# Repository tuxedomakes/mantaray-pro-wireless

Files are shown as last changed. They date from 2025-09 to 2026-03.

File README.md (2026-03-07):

# Grab your Mantaray Pro Wireless today from [my Ko-Fi page](https://ko-fi.com/s/1993d29fbd)!

# Mantaray Pro Wireless
This repo contains the build instructions, firmware, and 3D printable files needed to build, understand and modify the Mantaray Pro Wireless keyboard.

Firmware notes:
 - For defining pins higher than D10, you must use &gpioX Y notation (i.e. P1.07 -> &gpio0 7)
 - ZMK revision is currently pinned at v0.03 to avoid breakages in the build by linking to main
 - to use NFC pins as GPIO, CONFIG_NFCT_PINS_AS_GPIOS=y is set in unified .conf

BEGIN DOCUMENTATION

# Mantaray Pro Wireless DIY Edition: Build Guide

Welcome, and congratulations on starting your Mantaray Pro Wireless build! This guide will walk you through every step of the assembly process. Building a keyboard is a uniquely rewarding experience, and we're here to make it as smooth and enjoyable as possible.

**Estimated Build Time:** 1-3 hours  
**Difficulty:** Intermediate  

---

## Before You Begin: The Golden Rule

We know you're excited to get started, but please read this guide in its entirety before touching any components. Some steps require specific procedures and careful attention to detail. Understanding the full process beforehand will save you time and prevent potential mistakes. Trust us on this one!

---

## Part I: Preparation

### 1. Gather Your Tools

A good build starts with the right tools. Here’s what you’ll need to have on hand:

**Required:**
- Soldering Iron (a temperature-controlled model is highly recommended)
- Solder (low-temp, leaded solder like 63/37 is recommended for ease of use)
- Flush Cut Pliers / Snips
- Kapton Tape (or other heat-resistant tape)
- Tweezers  

**Recommended:**
- Solder Wick or a Solder Sucker (for fixing mistakes)
- Multimeter (to check for continuity as you go)
- A well-lit workspace

---

## Part II: PCB Assembly

### 2. Soldering the Microcontrollers (XIAO nRF52840 Plus)

This is the most critical step. The microcontrollers are the brains of your keyboard. Take your time, work carefully, and you'll do great.

⚠️ **Important Cautions:**
- Alignment is key. The microcontroller uses castellated pads, so it must be perfectly centered on the PCB pads.
- Use low heat. A low-temperature solder and a conservative iron temperature will prevent damage to the sensitive components.
- BE CAREFUL around the small black power switch on the PCB. Applying heat near it or touching it with your iron can damage it permanently.

**Procedure:**
1. **Identify Left & Right:** Your kit includes a Left (L) and Right (R) PCB, and a corresponding Left (L) and Right (R) microcontroller. The firmware is side-specific, so it's crucial to match them correctly.
2. **Position the Left Controller:** Place the left PCB on your work surface with the bottom side facing up (the side with the QR code). Place the left microcontroller onto its silkscreen outline.
3. **Align Perfectly:** Look closely at the castellated pads on the edge of the microcontroller. Align them so they are perfectly centered over the gold pads on the PCB. You should see an equal amount of the PCB pad on either side of each microcontroller pad.
4. **Tape it Down:** Once aligned, use a small piece of Kapton tape to hold the microcontroller firmly in place. This prevents it from shifting while you work.
5. **Tack Solder:** Solder just one pad on one side of the microcontroller. Then, check the alignment again. If it's shifted, simply re-melt that single solder joint and nudge the controller back into position.
6. **Secure the Other Side:** Once you're happy with the alignment, solder one pad on the opposite side to lock it in place. You can now carefully remove the tape.
7. **Finish Bottom Soldering:** Carefully solder the remaining castellated pads. Your goal is a strong, clean connection for each pad. Ensure no solder has "bridged" or accidentally connected two pads together.
8. **Solder Top Battery Pads:** Flip the board over to the top side. You will see cutouts where the microcontroller sits underneath. Carefully solder the battery pads on the microcontroller through these cutouts to the plated holes on the PCB. Ensure the positive (+) and negative (-) pads have a secure connection.
9. **Repeat for the Right Side:** Follow the exact same procedure (steps 2–8) for the right PCB and right microcontroller.

Give yourself a pat on the back. You just completed a precision soldering job!

---

### 3. Installing the Hotswap Sockets

Now for something a bit more relaxing. We'll install the sockets that allow you to change your switches anytime you want.

- **Orientation is Important:** Look at a hotswap socket. One side is square, while the other is chamfered. The white silkscreen outline on the PCB matches this shape.
- **Place and Solder:** Place a hotswap socket onto the PCB, matching its shape to the silkscreen outline. Solder both metal tabs to the PCB pads, ensuring the solder flows nicely to create a secure connection.  
  [TODO: Image showing the correct orientation of a hotswap socket on the PCB]
- **Repeat:** Continue this process for all 26 sockets on the left PCB, and all 26 sockets on the right PCB.

---

### 4. Installing the nice!view Displays

This step requires precision, but we'll break it down. The goal is to mount the display perfectly flush and vertical.

⚠️ **Critical Note:** The display pins must not protrude from the bottom of the PCB. The battery will sit directly underneath, and any protruding pins could puncture the battery, or cause a dangerous short circuit.

**Procedure (Start with the Left PCB):**
1. **Tape the Bottom:** Firmly press a piece of Kapton tape over the 5 display pin holes on the bottom of the PCB. This acts as a stopper for the pins.
2. **Prepare the Header Pins:** Grab one of the 5-pin headers. Using pliers or tweezers, push the black plastic spacer all the way to the top of the pins. When you hold the end of the pins vertically on a table, all 5 pins should touch the surface evenly. This ensures they are all the same length. If they aren’t adjust them and make it so.
3. **Insert the Pins:** From the top side of the PCB, insert the 5 pins into the display holes. The tape on the bottom will stop them from going through too far.
4. **Tack & Align:** Solder just one of the outer pins. Use a minimal amount of solder. Now, check that the row of pins is perfectly vertical and not leaning. If it is, reheat the joint and adjust.
5. **Check the Bottom:** Flip the PCB over. Confirm that no metal pin is poking through the tape. If one is, you must reheat the joints and reseat the pins until they are all flush.
6. **Solder the Top:** Once confirmed flush, solder the remaining 4 pins from the top. Again, use just enough solder to form a good joint. Too much solder will prevent the display from sitting flat.
7. **Solder the Bottom (Optional but Recommended):** Remove the tape from the bottom. To ensure the best connection, apply a tiny amount of solder to each pin-pad joint on the bottom. The goal is a flat, smooth joint with no sharp points.
8. **Remove the Spacer:** The black plastic spacer is no longer needed. Use tweezers or small pliers to gently wiggle it off the pins.
9. **Trim the Pins:** Place the nice!view display onto the pins. Mark where the top of the display's PCB meets the pins. Remove the display and use your flush cutters to trim the pins at your mark. The pins must not extend past the top of the display.  
   [TODO: Image showing how to mark and trim the display pins]
10. **Final Mount & Solder:** Place the display back onto the trimmed pins. Ensure it sits flat and is aligned parallel to the top and side edges of the PCB. Now, carefully solder each of the 5 pins to the display.  
    ⚠️ **Heat Warning:** Solder one pin at a time and allow the display to cool for a few seconds between each pin to avoid heat damage.

**Repeat for the Right Side.**

Whew, the hard parts are officially over. You’re on the home stretch now!

---

## Part III: Case Assembly

### 5. Installing the Heat-Set Inserts

These brass inserts provide durable mounting points for your PCB and future accessories.

1. **Set Your Iron:** Set your soldering iron to 410°F / 210°C. Make sure the tip is clean.
2. **Position the Insert:** Use tweezers to place an insert onto the tip of your iron. The tapered end should be facing away from the iron.
3. **Press it in:** Align the insert with one of the mounting holes in the 3D printed case. Gently and vertically press the iron down. The heat will melt the plastic, allowing the insert to sink into place.
4. **Hold and Remove:** Once the insert is flush with the surface, use your tweezers to hold it in place and pull your soldering iron straight out. This prevents the insert from coming out with the iron.
5. **Repeat:** Install all inserts:
   - 5 inserts on the inside of each bottom case half (for the PCB).
   - 4 inserts on the very bottom of each case half (for tenting accessories and mounts).

---

### 6. Testing Time!

It's time for a quick check to make sure everything is working before final assembly.

- Plug a USB-C cable into your computer and the other end into the XIAO microcontroller on the left PCB. The display should power on and show an image.
- Unplug the left side and test the right side in the same way.

If the displays light up, you're golden! If not, don't panic. Carefully re-check all your solder joints, especially for the microcontroller and display.

---

### 7. Battery Installation

🚨 **DANGER: READ THIS SECTION 3 TIMES** 🚨  
LiPo batteries can be dangerous and must be handled with the utmost care. The polarity (+ and -) of battery wires is **NOT STANDARDIZED**. Connecting a battery with reversed polarity can destroy your keyboard, cause a fire, and lead to serious injury or worse. **YOU ARE RESPONSIBLE FOR VERIFYING POLARITY.**

**Procedure:**
1. **SWITCH OFF:** Ensure the power switch on the PCB is in the OFF position (pushed down, away from the USB port).
2. **VERIFY POLARITY:** Look at the battery connector on your PCB. It is marked with a **+**. Now look at the wires coming from your battery's JST connector. The **RED wire (+) MUST align with the + mark on the PCB.**
3. **IF POLARITY IS WRONG:** You must fix it before plugging it in.  
   - **Option 1 (Preferred):** Use tweezers to carefully lift the plastic tabs on the JST connector and pull out the metal crimps. Re-insert them in the correct orientation. Work on one wire at a time. NEVER let the exposed positive and negative wires touch.  
   - **Option 2:** Carefully cut, swap, and re-solder the wires. Insulate each connection thoroughly with heat shrink. NEVER let the exposed positive and negative wires touch.
4. **Connect and Test:** Once you have triple-checked the polarity, plug the battery into the PCB. Flip the power switch to the ON position. The display should turn on.
5. **SWITCH OFF AGAIN:** Turn the power switch back to the OFF position for final assembly.
6. **Repeat for the right side.**

---

### 8. Final Assembly

1. **Place the Battery:** Take the left bottom case and place the battery into the dedicated battery slot. The wires should route through the small cutout.
2. **Install Battery Cover:** Place the plastic battery protection cover over the battery and press it firmly into place until it is fully seated. It has a cutout that matches the orientation of the battery slot.
3. **Insert the PCB:** Insert the PCB into the case at an angle, seating the power switch side first. This is necessary to clear the switch housing.  
   [TODO: Image showing the angled insertion of the PCB into the case]
4. **Secure the PCB:** Align the PCB mounting holes with the heat-set inserts. Secure the PCB using the five M2 screws. Do not overtighten.
5. **Repeat for the right side.**

---

## Part IV: Finishing Touches

### 9. Attach the Top Case
Take the top case/plate for each side and carefully align it over the bottom case. It's a tight snap-fit, so work your way around the edges, gently pressing down until it's fully seated.

### 10. Apply Rubber Feet
Flip the keyboard over. Apply four of the adhesive non-slip rubber feet to the designated spots on the bottom of each half.

### 11. Install Switches
Gently press your Kailh Choc V1 switches through the top plate and into the hotswap sockets. Before installing each switch, check to ensure its two pins are straight. If they're bent, gently straighten them before pressing the switch in.

### 12. Install Keycaps
Press your keycaps firmly onto the switch stems. This is the final, satisfying step!

---

# You're Done!

Congratulations! You've successfully built your Mantaray Pro Wireless keyboard. Take a moment to admire your work. We hope you love the feel of a keyboard built with your own two hands.

**Next Steps:** To learn how to use your new keyboard, connect to your devices via Bluetooth, and customize your layout, please refer to the **Mantaray Pro Wireless User Manual** (TODO: add link here).

---

**Happy typing!**

---

# Under what license is this released?
Hardware design files, including electronics and mechanical files, are released under OHL CERN v2-S. Check the LICENSE file for full details.

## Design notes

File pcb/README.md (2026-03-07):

PCB files for the Mantaray Pro Wireless.

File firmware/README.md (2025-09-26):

To flash the firmware to your keyboard, connect one half of your board to your computer then double click the reset button on the bottom of the case. You should see a removable drive appear. Drag the corresponding firmware file to that drive and wait for it to reboot.

Once your keyboard reboots, you can move on to flashing the other side. Be sure to flash the correct firmware file for each side (i.e. left for left board, right for right board).

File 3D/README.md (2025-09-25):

These are the case files for the Mantaray Pro Wireless Keyboard. You can also download and print them on [makerworld](https://makerworld.com/en/models/1827495-mantaray-pro-wireless-split-wireless-keyboard#profileId-1951110)

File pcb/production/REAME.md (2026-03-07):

Production files for Mantaray Pro Wireless.

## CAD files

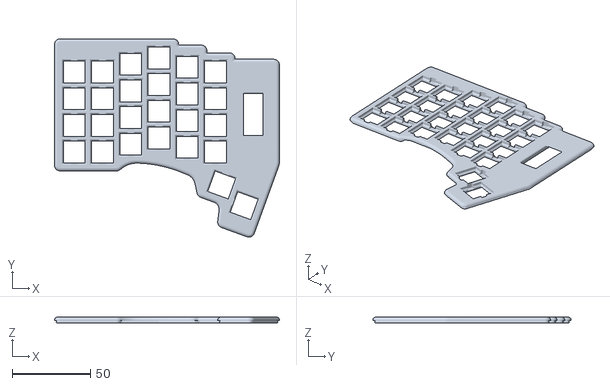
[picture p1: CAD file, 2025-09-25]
3D/Plate Left.stl
143.4 x 126.4 x 3.75

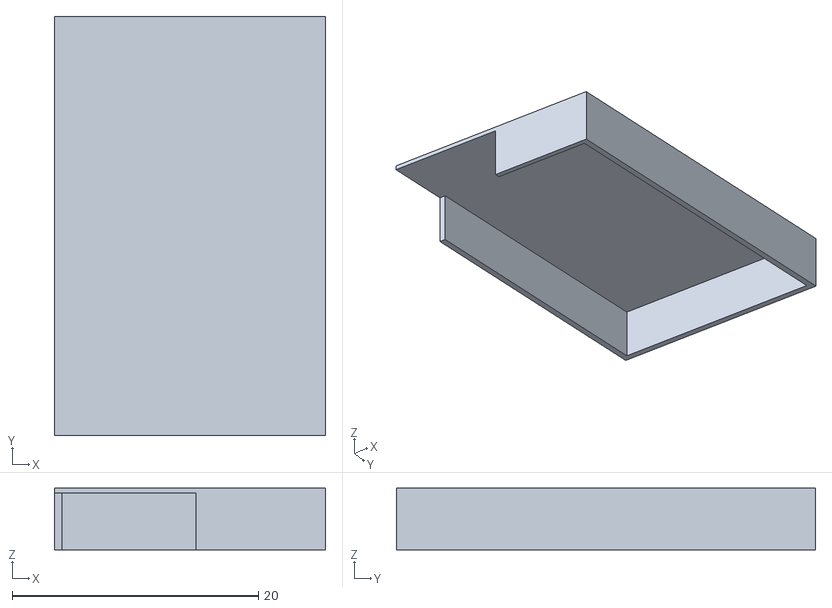
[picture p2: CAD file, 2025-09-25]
3D/battery cover.stl
22.0 x 34.0 x 5.00

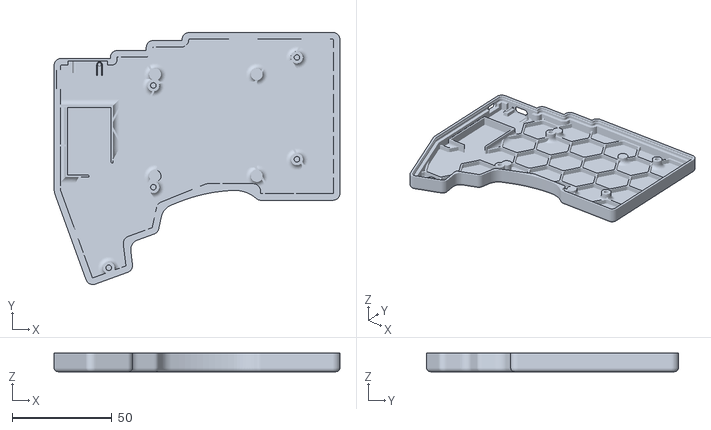
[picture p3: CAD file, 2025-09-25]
3D/Case right.stl
143.4 x 126.4 x 9.30

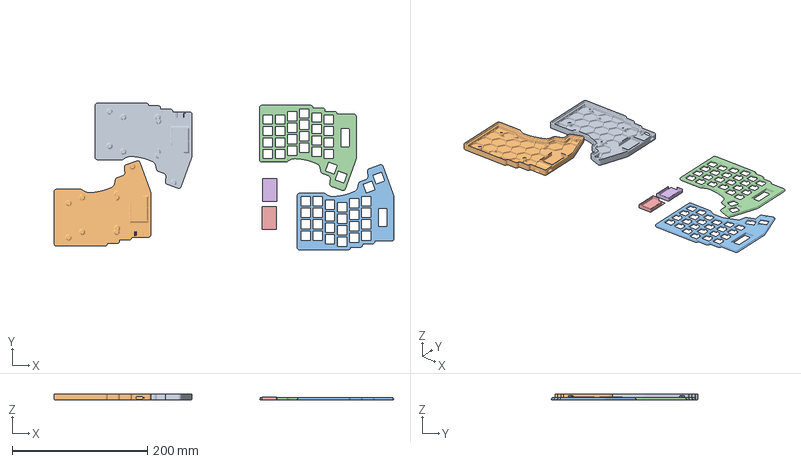
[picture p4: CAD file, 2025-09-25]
3D/Case Parts X1C Matte White.3mf
503.5 x 217.6 x 9.30 mm
Case Left.stl
Case right.stl
Plate Left.stl
plate right.stl
Battery Cover Right.stl
battery cover.stl

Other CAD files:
3D/plate right.stl
3D/Battery Cover Right.stl
3D/Case Left.stl

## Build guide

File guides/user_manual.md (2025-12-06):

## 1\. Welcome to the Mantaray Pro Wireless

Congratulations on your new Mantaray Pro Wireless\! This manual will guide you through the setup, features, and customization of your new keyboard to help you unlock its full potential.

Note: This manual is not an assembly guide for the Mantaray Pro Wireless DIY Edition. You can find the build guide [here](https://tuxedodevices.com/blogs/guides/mantaray-pro-wireless-diy-edition-build-guide).

* USB C Port  
* Power & Connection Status  
* Selected Bluetooth Profile  
* Active Layer  
* Nice\!View Display  
* Power Switch  
* LED (disabled by default to extend battery life)

## 2\. What's in the Box?

* Mantaray Pro Wireless (Pre-Assembled)  
  * Assembled Mantaray Pro Wireless Keyboard  
    * **If located outside the United States**, batteries will not be included with your order  
* Mantaray Pro Wireless DIY Edition  
  * Left & Right 3D printed case  
  * Left & Right PCBs  
  * 2 x XIAO nRF52840 Plus Microcontrollers  
  * 2 x 200mah LiPo Batteries   
    * **If located outside the United States**, batteries will not be included with your order  
  * 52 x Kailh Choc Hotswap Sockets  
  * 8 x Non-slip Rubber Feet  
  * 2 x nice\!view Displays \+ Headers  
  * 10 x M2 Screws  
  * 18 x M2 Heat Set Inserts  
  * (If Selected) 1 Set of Choc v1 Keycaps  
  * (If Selected) 52 x Kailh Choc v1 Switches

## 3\. Getting Started: First Use

**Note:** If you have the Mantaray Pro Wireless DIY Edition please follow the [build guide](https://tuxedodevices.com/blogs/guides/mantaray-pro-wireless-diy-edition-build-guide) before proceeding.

* Charging the Keyboard:  
  * Connect the included USB-C cable to the port on the back of the keyboard and plug the other end into a USB power source.  
  * A full charge takes approximately 2-3 hours and provides up to 21 days of battery life on the left board, and 3 months of battery on the right\*\*. These are estimates, and actual battery life is dependent on usage.  
* Powering On/Off:  
  * On Position: Up, toward the USB-C port  
  * Off Position: Down, toward the display  
  * Locate the power switch on the edges of the keyboard, near the display.  
  * Slide the switches to the "ON" position to turn on the boards.  
* Connecting to Your Device:  
  * Bluetooth   
    * Ensure Bluetooth is enabled on the device you wish to connect to.  
    * On your device, select "Mantaray Pro W" from the list of available Bluetooth devices. Follow any on-screen prompts to complete the pairing.  
    * **Pro Tip:** You can pair up to five different devices at a time. To switch between paired devices, simply press the corresponding L1 \+ Number key (e.g. L1 \+ 2).  
  * Wired (USB-C)  
    * Connect the left board to your computer using a USB-C cable.  
      * The keyboard will automatically switch to wired mode and begin charging.  
        * **WARNING:** Keeping a wireless keyboard plugged in constantly keeps its internal lithium battery at 100% – leading to accelerated degradation and increased fire risk. To stay safe, follow proper battery care practices, switch off, disconnect, or remove the battery when not using wireless mode.  
        * **Note:** The Mantaray Pro Wireless uses ZMK to facilitate communication between the board halves. The left half sends key presses directly to your computer via Bluetooth or USB, depending on how it’s currently connected. The right half sends keypresses to the left half, which then forwards them to the computer. Communication will always happen through the left side of the board. Because of this, **the left half may be used independently, and wired, while the right half relies on the presence of the left** half to facilitate communication. This is currently a limitation of ZMK.

## 4\. Bluetooth Profiles

You can use up to 5 Bluetooth profiles at a time, and switch between them to use your keyboard on different devices.

* Switching Profiles  
  * Press L1 \+ 1-5 to select a profile

## 4\. Keyboard Layout and Function Keys

**Base Layer**

**Symbol Layer**

**Media Layer**

* Indicator Light:  
  * An indicator LED is present near the USB-C port. It is disabled by default to maximize battery life; however, it can be enabled by customizing your device firmware via ZMK.

## 5\. Advanced Features and Customization

You can use the ZMK Studio web app to easily remap your keys, add new layers, and more.

* Key Remapping:  
  * Plug the left board into your computer  
  * In your browser, open [ZMK Studio](https://zmk.studio/)  
  * Click “USB”  
  * Select “Mantaray Pro W” from the list of available devices  
  * Remap your keys and add layers  
    * For more detailed information on using ZMK Studio, refer to the [official documentation](https://zmk.dev/docs/features/studio).

## 7\. Troubleshooting

Common Issues and Solutions:

Keyboard Won't Connect

* Check that the keyboard is powered on.  
* Ensure the battery is charged.  
* Confirm the correct connection method is selected (Bluetooth or Wired).  
* Your Bluetooth pairing keys may be out of sync. You can **reset the Bluetooth pairing keys for all profiles by holding Q \+ P** for a few seconds.  
* Ensure no other devices are trying to connect to the keyboard.  
* Move the keyboard closer to your device.  
* Avoid placing large metal objects between the keyboard and your device.  
* Check for other wireless devices that may interfere with the signal. Wireless dongles and other Bluetooth devices may be the culprit.

## 8\. Safety and Maintenance

* General Safety Precautions:  
  * This product contains lithium batteries. Do not expose to extreme temperatures or liquids.  
* Cleaning Instructions:  
  * Clean with a soft, dry cloth. For stubborn dirt, use a small brush and a small amount of isopropyl alcohol. Always remove your battery before deep cleaning.  
* Battery Safety:  
  * Recharging your battery should only be done at 50ma, with an absolute maximum of 100ma. More than this may cause damage to your keyboard and/or battery.

## 9\. Contact and Support

* Contact Information:  
  * Customer Support Email: tuxedomakes@gmail.com  
  * [Contact Us Form](https://tuxedodevices.com/pages/contact)  
  * [Tuxedo Devices Discord](https://discord.gg/HABg37gjrd)

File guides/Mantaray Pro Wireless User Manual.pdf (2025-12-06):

## 1. Welcome to the Mantaray Pro Wireless

Congratulations on your new Mantaray Pro Wireless! This manual will guide you through the setup, features, and customization of your new keyboard to help you unlock its full potential.

Note: This manual is not an assembly guide for the Mantaray Pro Wireless DIY Edition. You can find the build guide here.

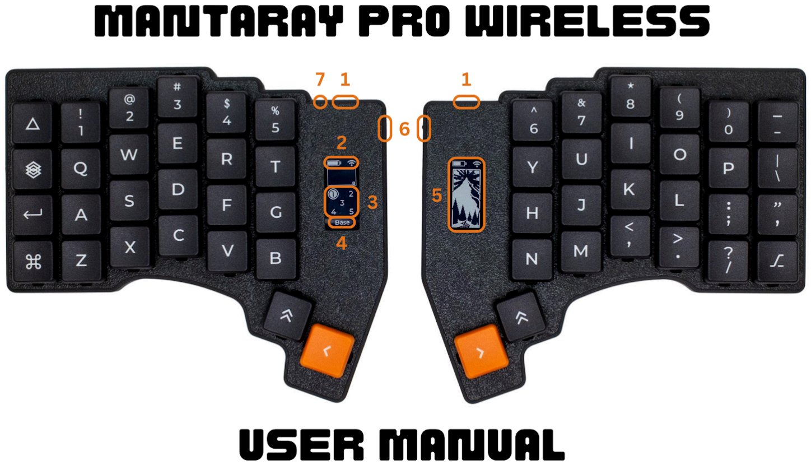
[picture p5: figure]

- USB C Port
- Power & Connection Status
- Selected Bluetooth Profile
- Active Layer
- Nice!View Display
- Power Switch
- LED (disabled by default to extend battery life)

## 2. What's in the Box?

- Mantaray Pro Wireless (Pre-Assembled)
- Assembled Mantaray Pro Wireless Keyboard

- If located outside the United States, batteries will not be included with your order
- Mantaray Pro Wireless DIY Edition
- Left & Right 3D printed case
- Left & Right PCBs
- 2 x XIAO nRF52840 Plus Microcontrollers
- 2 x 200mah LiPo Batteries
- If located outside the United States, batteries will not be included with your order
- 52 x Kailh Choc Hotswap Sockets
- 8 x Non-slip Rubber Feet
- 2 x nice!view Displays + Headers
- 10 x M2 Screws
- 18 x M2 Heat Set Inserts
- (If Selected) 1 Set of Choc v1 Keycaps
- (If Selected) 52 x Kailh Choc v1 Switches

## 3. Getting Started: First Use

Note: If you have the Mantaray Pro Wireless DIY Edition please follow the build guide before proceeding.

- Charging the Keyboard:
- Connect the included USB-C cable to the port on the back of the keyboard and plug the other end into a USB power source.
- A full charge takes approximately 2-3 hours and provides up to 21 days of battery life on the left board, and 3 months of battery on the right**. These are estimates, and actual battery life is dependent on usage.
- Powering On/Off:
- On Position: Up, toward the USB-C port
- Off Position: Down, toward the display
- Locate the power switch on the edges of the keyboard, near the display.
- Slide the switches to the "ON" position to turn on the boards.
- Connecting to Your Device:
- Bluetooth
- Ensure Bluetooth is enabled on the device you wish to connect to.

- On your device, select "Mantaray Pro W" from the list of available Bluetooth devices. Follow any on-screen prompts to complete the pairing.
- Pro Tip: You can pair up to five different devices at a time. To switch between paired devices, simply press the corresponding L1 + Number key (e.g. L1 + 2).
- Wired (USB-C)
- Connect the left board to your computer using a USB-C cable.
- The keyboard will automatically switch to wired mode and begin charging.
- WARNING: Keeping a wireless keyboard plugged in constantly keeps its internal lithium battery at 100% – leading to accelerated degradation and increased fire risk. To stay safe, follow proper battery care practices, switch off, disconnect, or remove the battery when not using wireless mode.
- Note: The Mantaray Pro Wireless uses ZMK to facilitate communication between the board halves. The left half sends key presses directly to your computer via Bluetooth or USB, depending on how it’s currently connected. The right half sends keypresses to the left half, which then forwards them to the computer. Communication will always happen through the left side of the board. Because of this, the left half may be used independently, and wired, while the right half relies on the presence of the left half to facilitate communication. This is currently a limitation of ZMK.

## 4. Bluetooth Profiles

You can use up to 5 Bluetooth profiles at a time, and switch between them to use your keyboard on different devices.

- Switching Profiles
- Press L1 + 1-5 to select a profile

## 4. Keyboard Layout and Function Keys

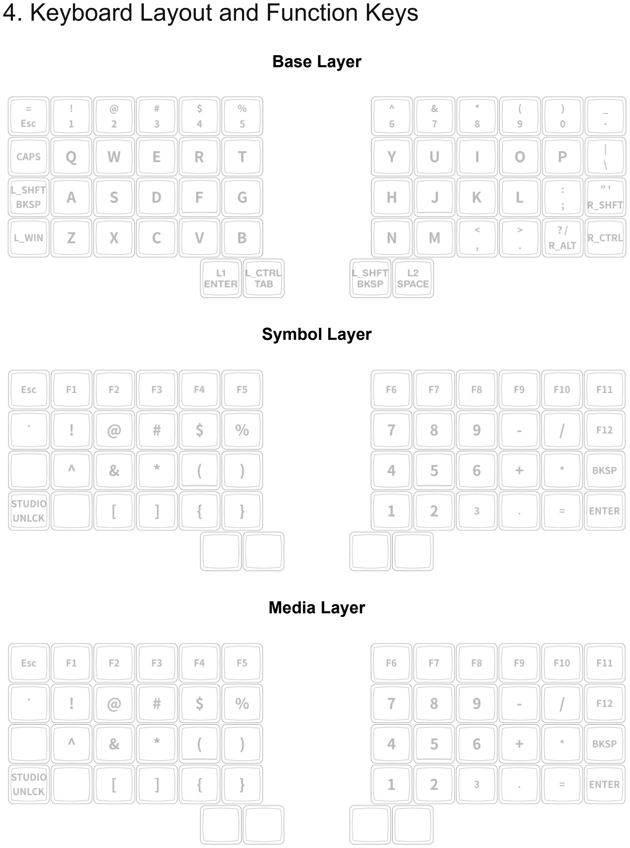
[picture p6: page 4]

Base Layer

Symbol Layer

Media Layer

- Indicator Light:
- An indicator LED is present near the USB-C port. It is disabled by default to maximize battery life; however, it can be enabled by customizing your device firmware via ZMK.

## 5. Advanced Features and Customization

You can use the ZMK Studio web app to easily remap your keys, add new layers, and more.

- Key Remapping:
- Plug the left board into your computer
- In your browser, open ZMK Studio
- Click “USB”
- Select “Mantaray Pro W” from the list of available devices
- Remap your keys and add layers
- For more detailed information on using ZMK Studio, refer to the official documentation.

## 7. Troubleshooting

Common Issues and Solutions:

Keyboard Won't Connect

- Check that the keyboard is powered on.
- Ensure the battery is charged.
- Confirm the correct connection method is selected (Bluetooth or Wired).
- Your Bluetooth pairing keys may be out of sync. You can reset the Bluetooth pairing keys for all profiles by holding Q + P for a few seconds.
- Ensure no other devices are trying to connect to the keyboard.
- Move the keyboard closer to your device.
- Avoid placing large metal objects between the keyboard and your device.
- Check for other wireless devices that may interfere with the signal. Wireless dongles and other Bluetooth devices may be the culprit.

## 8. Safety and Maintenance

- General Safety Precautions:
- This product contains lithium batteries. Do not expose to extreme temperatures or liquids.
- Cleaning Instructions:
- Clean with a soft, dry cloth. For stubborn dirt, use a small brush and a small amount of isopropyl alcohol. Always remove your battery before deep cleaning.
- Battery Safety:
- Recharging your battery should only be done at 50ma, with an absolute maximum of 100ma. More than this may cause damage to your keyboard and/or battery.

## 9. Contact and Support

- Contact Information:
- Customer Support Email: tuxedomakes@gmail.com
- Contact Us Form
- Tuxedo Devices Discord
●

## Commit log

2025-09-25 Add 3D models
    [Battery Cover Right.stl, Case Left.stl, Case Parts X1C Matte White.3mf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]
2026-03-07 Initial commit of PCB files
    [mantaray_pro_wireless_panel_xiao.kicad_sch]
2026-03-07 Upload of latest firmware
    Adds firmware for mantaray pro wireless left and right (latest) along with the reset firmware.
